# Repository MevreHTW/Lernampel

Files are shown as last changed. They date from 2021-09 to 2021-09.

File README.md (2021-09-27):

# Lernampel
Dieses Projekt wurde im Rahmen der Vorlesung Methoden der Wissensverarbeitung bei Frau Prof. Dr. Willner an der HTW Berlin umgesetzt. Zu dem Projektteam gehören: Mevre Tunca, Marianne Bähne, Martin König und Jonas Render.

Um den Code auf den Octopus zu flashen muss die Arduino IDE zuerst installiert werden. Die Aneitungen für die Installation finden sich hier:

Windows: https://www.umwelt-campus.de/fileadmin/Umwelt-Campus/IoT-Werkstatt/octopus/Quickstart.pdf

Mac: https://www.umwelt-campus.de/fileadmin/Umwelt-Campus/IoT-Werkstatt/octopus/QuickstartMacOS.pdf

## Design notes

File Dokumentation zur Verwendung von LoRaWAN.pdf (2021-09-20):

## Dokumentation zur Verwendung von LoRaWAN

Um die Lautstärke und Personenzahl von der Ampel und der Schranke in einem Dashboard darstellen zu können müssen sie per LoRaWAN versendet werden. Hierfür sollte zuerst der Account erstellt und das Gateway angeschlossen werden.

Erstellung einer Application/eines End devices auf thingsnetwork.org
Zur Erstellung einer Application den nachfolgenden Schritten folgen:
1. Auf der Website https://www.thethingsnetwork.org/ einen Account erstellen.
2. Auf den Accountnamen oben rechts klicken und dann Console auswählen. Account: jonasR95
pw: foddo0-giqraz-gAdbir
3. Europe 1 auswählen.
4. Go to Applications klicken.
5. Add Application klicken.
6. ApplicationID und Namen vergeben (kann individuell gewählt werden) und auf Create application klicken.
7. Add end device auswählen.
8. Bei Register end device in der Menüleiste manually auswählen und die Werte des Screenshots für LoRaWAN Version und Frequency plan auswählen, danach DevEUI, AppEUI und AppKey generieren lassen, falls gewünscht device ID anpassen.
9. Auf register end device klicken

Schritt 1:

Schritt 2:

Schritt 3:

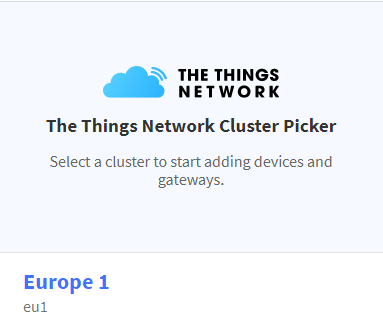
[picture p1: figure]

Schritt 4:

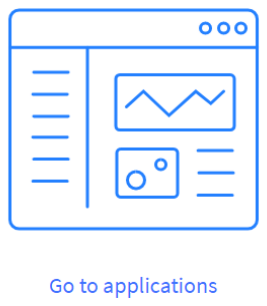
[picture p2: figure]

Schritt 5:

Schritt 6:

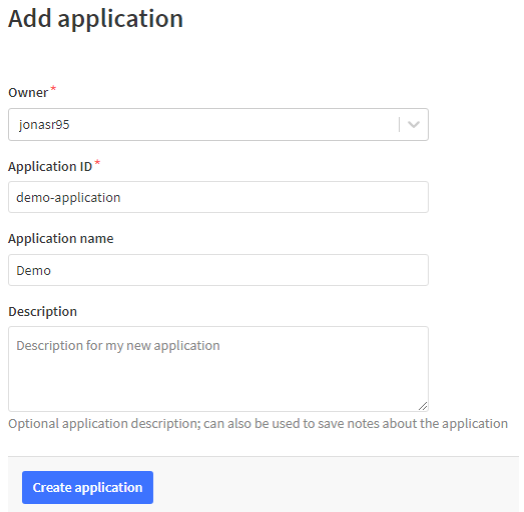
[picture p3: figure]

Schritt 7:

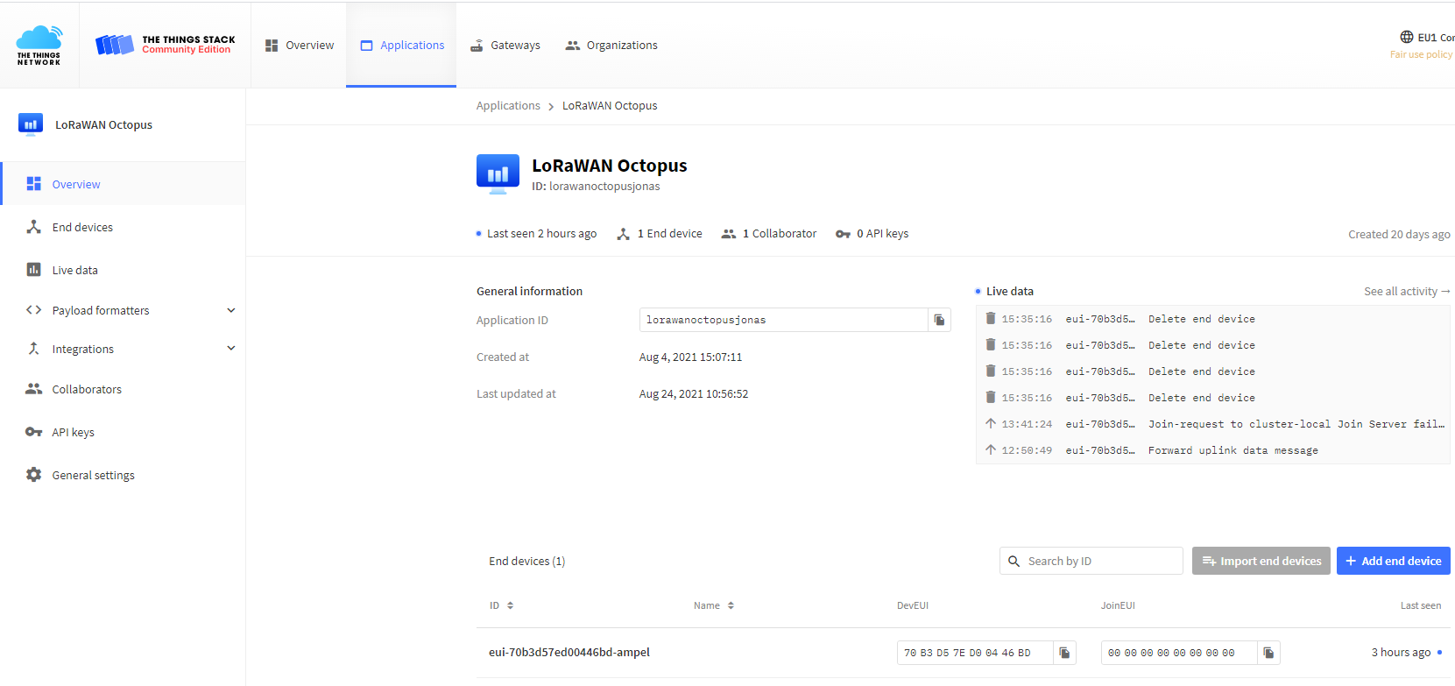
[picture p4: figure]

Schritt 8:

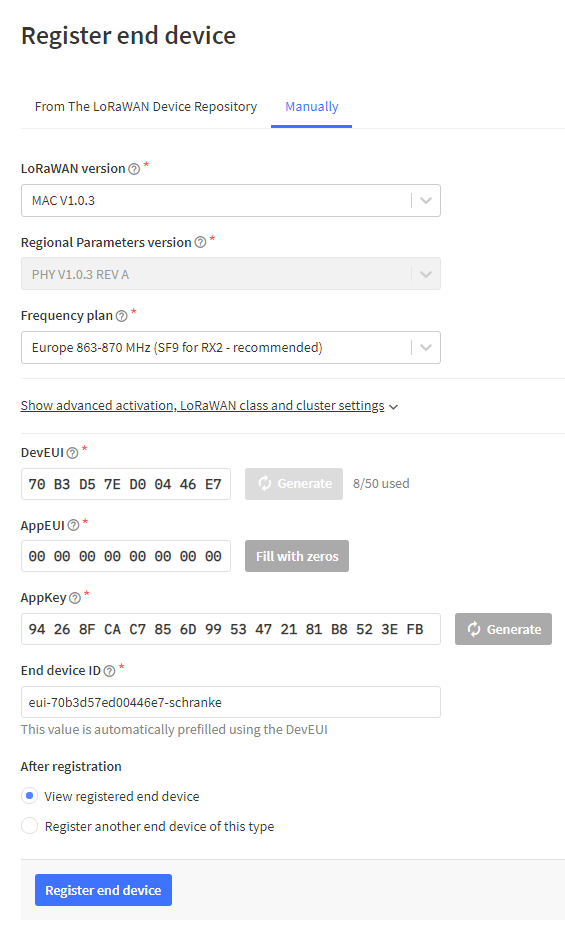
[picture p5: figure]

Einrichtung des LoRaWAN Gateways
Um die per LoRaWAN versendeten Daten im Internet sehen zu können müssen wir das LoRaWAN Gateway entsprechend einrichten. Hierfür wird das The Things Indoor Gateway benötigt. Zur Einrichtung bitte die folgenden Schritten befolgen:
1. Den RESET Button für 5 sekunden gedrückt halten bis die LED grün und rot blinkt.
2. Den SETUP Button für 10 sekunden gedrückt halten bis die LED rot blinkt.
3. Nach diesen Schritten befindet sich das Gateway im Einrichtungsmodus und sendet ein WiFi Signal.
4. Nach dem WiFi Netzwerk mit dem Namen MINIHUB-XXXXXX (das sind die letzten sechs stellen der Gateway EUI) suchen und mit dem Netzwerk verbinden.
5. Wenn eine Verbindung mit dem Netzwerk besteht im Browser 192.168.4.1 eingeben.
6. Auf der Seite das eigene Netzwerk suchen, auswählen und das Passwort für das Netzwerk eintragen.
7. Save & Reboot klicken.
8. Das Gateway startet neu und verbindet sich mit dem Netzwerk. Dafür einige Minuten warten, bis die Verbindung hergestellt wurde.

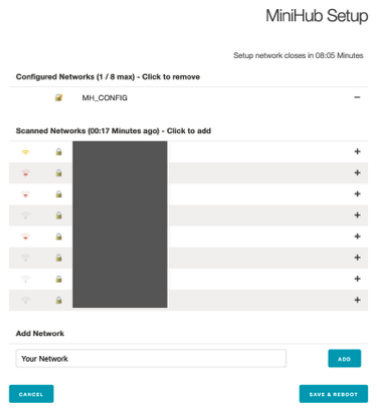
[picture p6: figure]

Quelle: https://www.thethingsindustries.com/docs/gateways/thethingsindoorgateway/

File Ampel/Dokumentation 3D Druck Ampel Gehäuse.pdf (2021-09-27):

## Dokumentation zum 3D Druck des Gehäuses für die Ampel

Was wird benötigt?
Um das Gehäuse drucken zu können wird ein 3D Drucker benötigt. Je nach Drucker unterscheidet sich die vorgehensweise, daher ist diese Anleitung sehr allgemein gehalten. 3 X .stl - Dateien (GitHub)
1 X Filament (schwarz)
1 X Filament (transparent)
8 X Gewindeeinsätze M3
6 X Schrauben M3 10 mm
2 X Schrauben M3 35 mm
1 X Spitzzange
1 X Teelicht

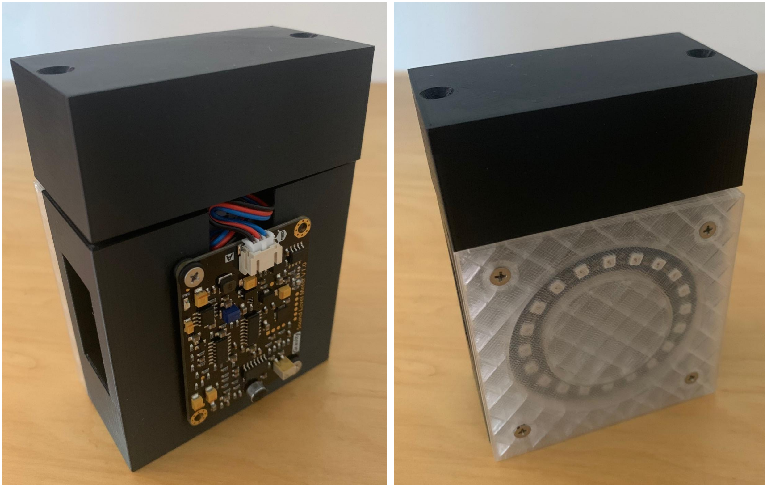
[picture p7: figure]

Druck der Dateien
Die .stl - Dateien aus GitHub herunterladen und slicen (je nach Drucker unterschiedliche vorgehensweise). Die beiden Dateien Ampel_Deckel und Ampel_Hauptteil sollten mit dem schwarzen Filament gedruckt werden. Die Datei Ampel_Abdeckung_LED Ring sollte mit dem transparenten Filament gedruckt werden.
Nach dem Druck aller drei Teile wie folgt vorgehen:
1. Eventuell müssen Stützstrukturen entfernt werden
2. Gewindeeinsätze in alle Löcher des Hauptteils montieren, hierzu:
a. Schraube in den Gewindeeinsatz eindrehen
b. Mit der Spitzzange die Schraube fixieren und den Gewindeeinsatz über dem Teelicht erhitzen
c. Gewindeeinsatz möglichst gerade in die jeweiligen Löcher des Hauptteils drücken
3. Hardware in die Hülle einbauen und mit den Schrauben fixieren. Der LED Ring kommt auf die Vorderseite (mit vier Schrauben), der Sensor zum Messen der Lautstärke auf die Rückseite (mit zwei Schrauben), hierfür die 10 mm Schrauben verwenden. Der Deckel wird mit den 35 mm Schrauben fixiert.

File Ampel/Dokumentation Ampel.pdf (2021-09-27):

## Dokumentation zur Entwicklung der Ampel

Was wird benötigt?
1 X IoT Octopus
1 X LoRa-Wings mit verlöteter Antenne
1 X Analog Sound Level Meter (https://www.mouser.de/ProductDetail/DFRobot/SEN0232?qs=r5DSvlrkXmJSkxvy12pSNQ%3D%3D)
1 X Grove - RGB LED Ring (20 - WS2813 Mini) (https://wiki.seeedstudio.com/Grove%20-%20RGB%20LED%20Ring%20%2820%20-%20WS2813%20Mini%29/) 2 X Jumper Kabel (digital)
1 X Jumper Kabel (analog)
3 X einfache Kabel
1 X Mini USB Kabel
1 X LoRaWAN Gateway - siehe Anleitung Dokumentation zur Verwendung von LoRaWAN

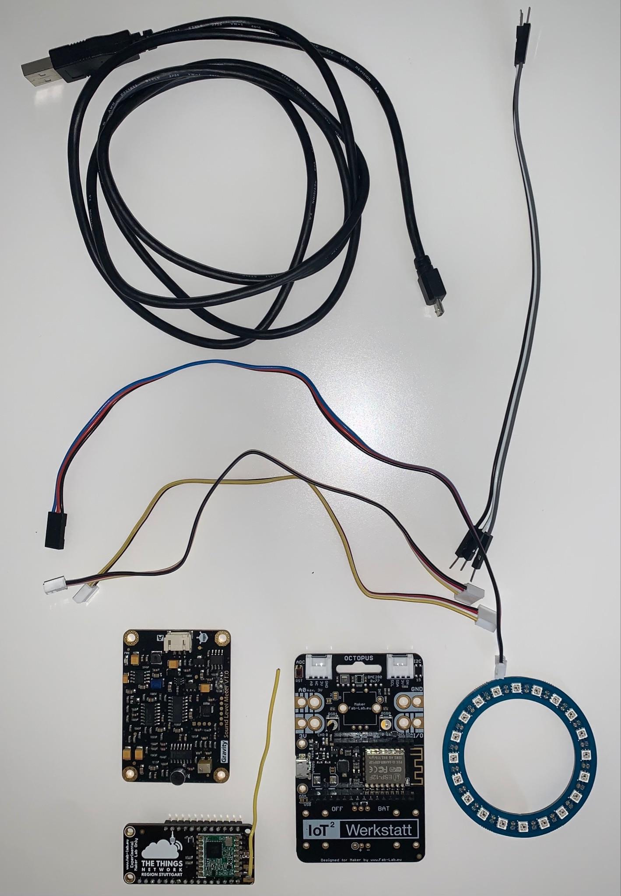
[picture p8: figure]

Allgemeine Hinweise und Funktionsweise der Ampel
Nachfolgend wird beschrieben wie die Hardware vorbereitet und der Code übertragen werden kann. Hierfür werden zunächst die Schritte erläutert und nachfolgend auch durch Bilder/Screenshots dargestellt.
Die Ampel misst die Lautstärke alle 250 Millisekunden. Je nach eingestellten Grenzwerten und aktueller Lautstärke leuchtet die Ampel rot, gelb oder grün. Alle 60 Sekunden wird die durchschnittliche Lautstärke mittels LoRaWAN versendet. Wenn dies geschieht leuchtet die Ampel blau, während dieser Zeit wird keine Lautstärke gemessen.

Hardware vorbereiten
Wir beginnen damit alle Bauteile an den Octopus anzuschließen. Hierbei wie folgt vorgehen:
1. LoRa-Wings auf den Octopus stecken.
2. Den LED Ring mit einem digitalen Jumper-Kabel mit dem Grove I²C Anschluss (oben rechts) verbinden.
3. Das analoge Jumper Kabel mit den Sound Sensor verbinden und das digitale Jumper Kabel mit dem analogen Anschluss des Octopus verbinden.
4. Nun das analoge - und digitale Jumper Kabel miteinander verbinden, hierzu die Beschriftung am Anschluss des Sound Sensors und Octopus beachten: (Achtung die Farben können je nach Kabel unterschiedlich sein)
Beschriftung am Sound Sensor | Beschriftung am Octopus
A (blau) | A0 (gelb)
+ (rot) | 3V (rot)
- (schwarz) | GND (schwarz)
nicht verbinden | NC (weiß)
5. Das Mini USB Kabel mit dem Octopus verbinden

Fotos zu den einzelnen Schritten:
Schritt 1:

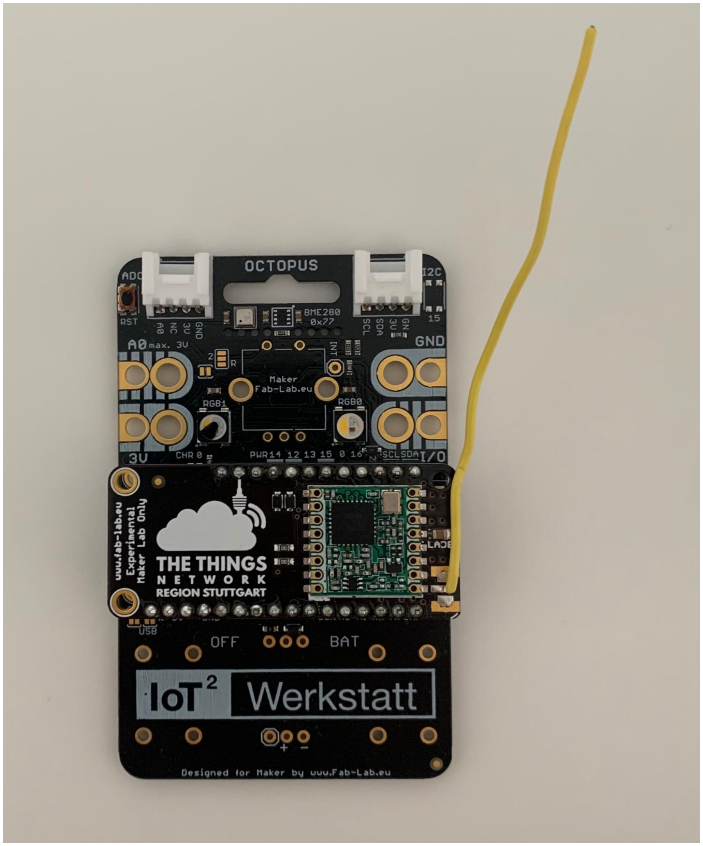
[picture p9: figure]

Schritt 2:

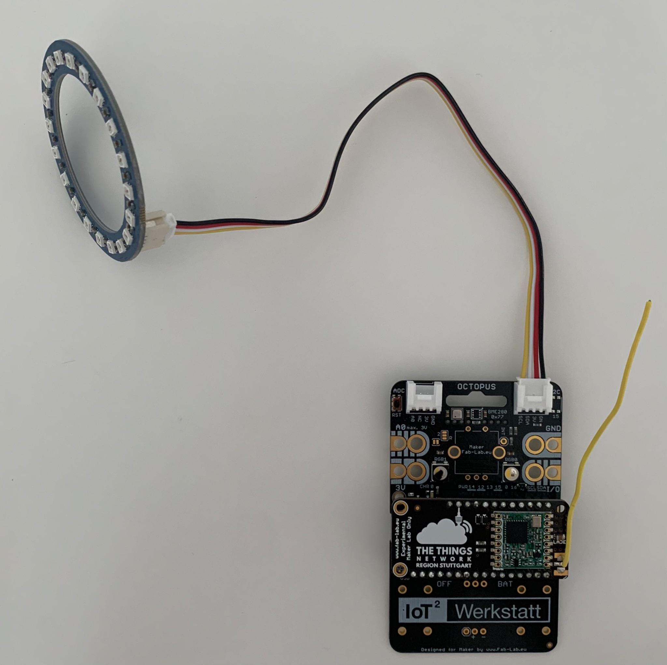
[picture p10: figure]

Schritt 3:

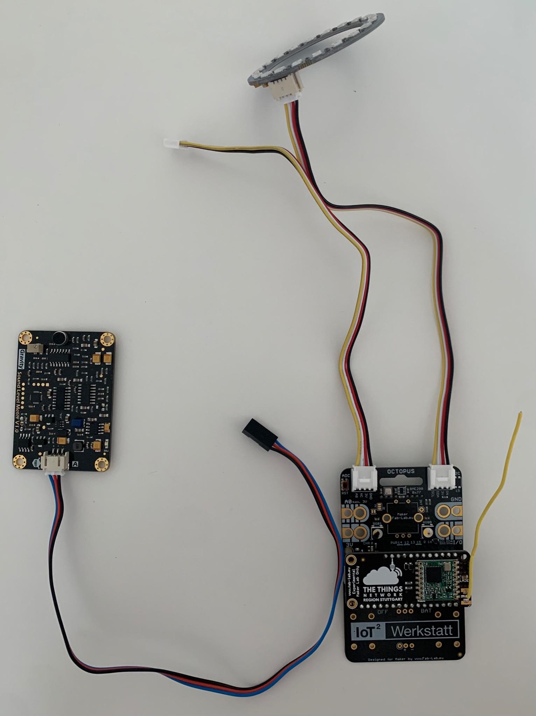
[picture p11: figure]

Schritt 4:

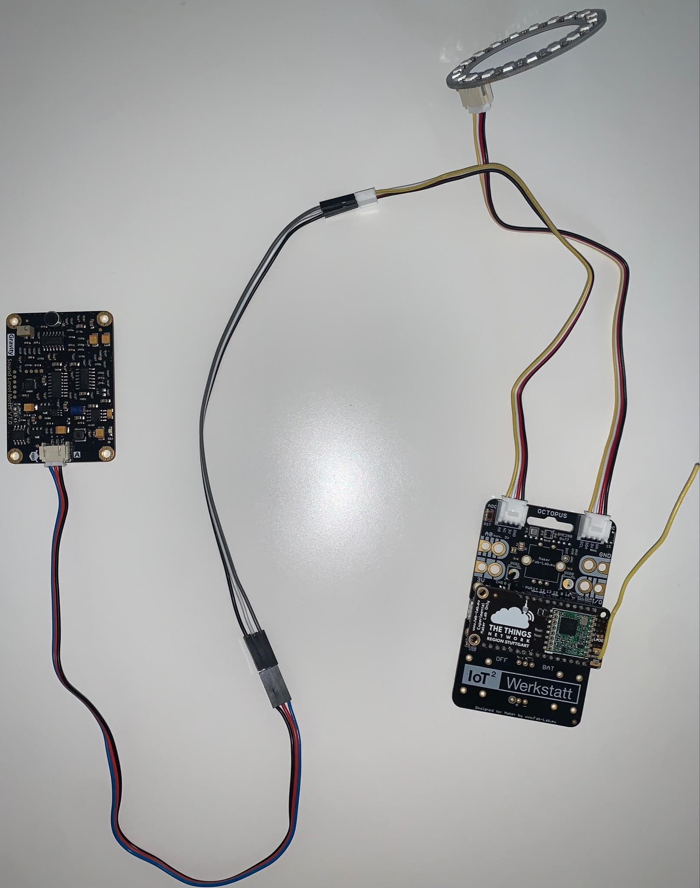
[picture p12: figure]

Anschluss am Sound Sensor:

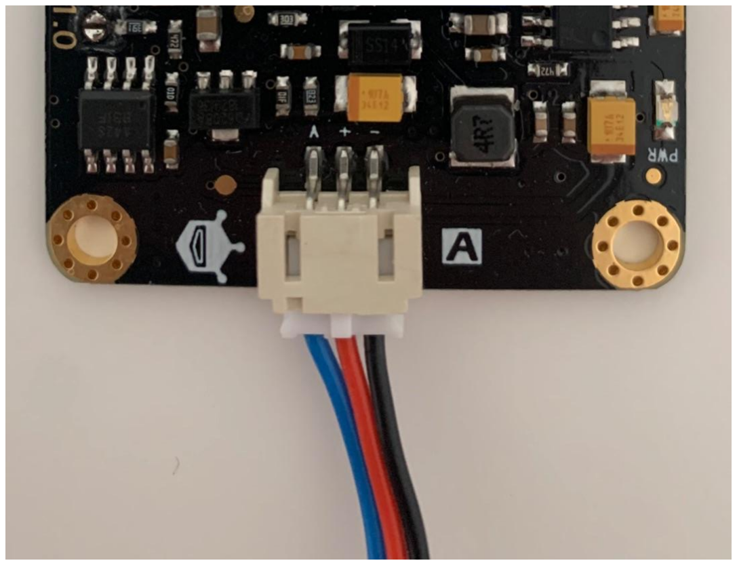
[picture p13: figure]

Anschluss am Octopus:

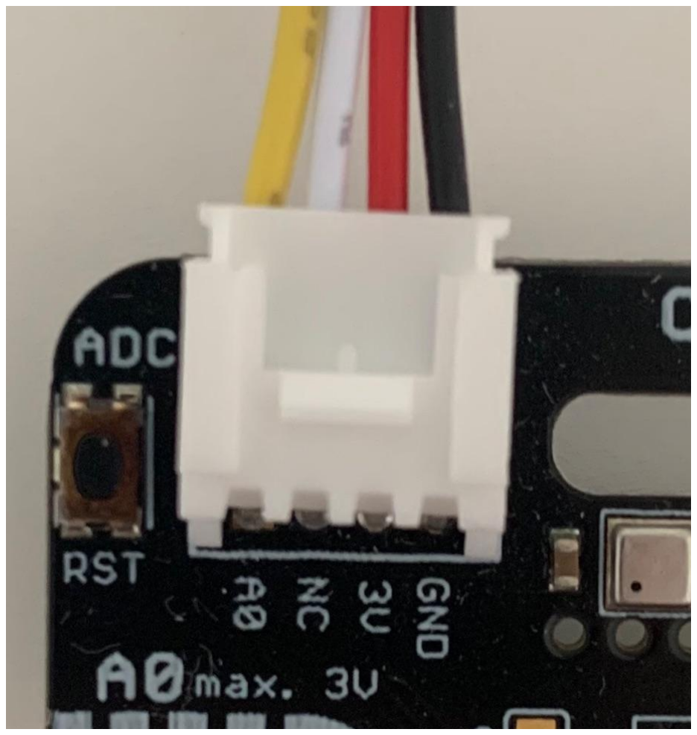
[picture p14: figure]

Schritt 5:

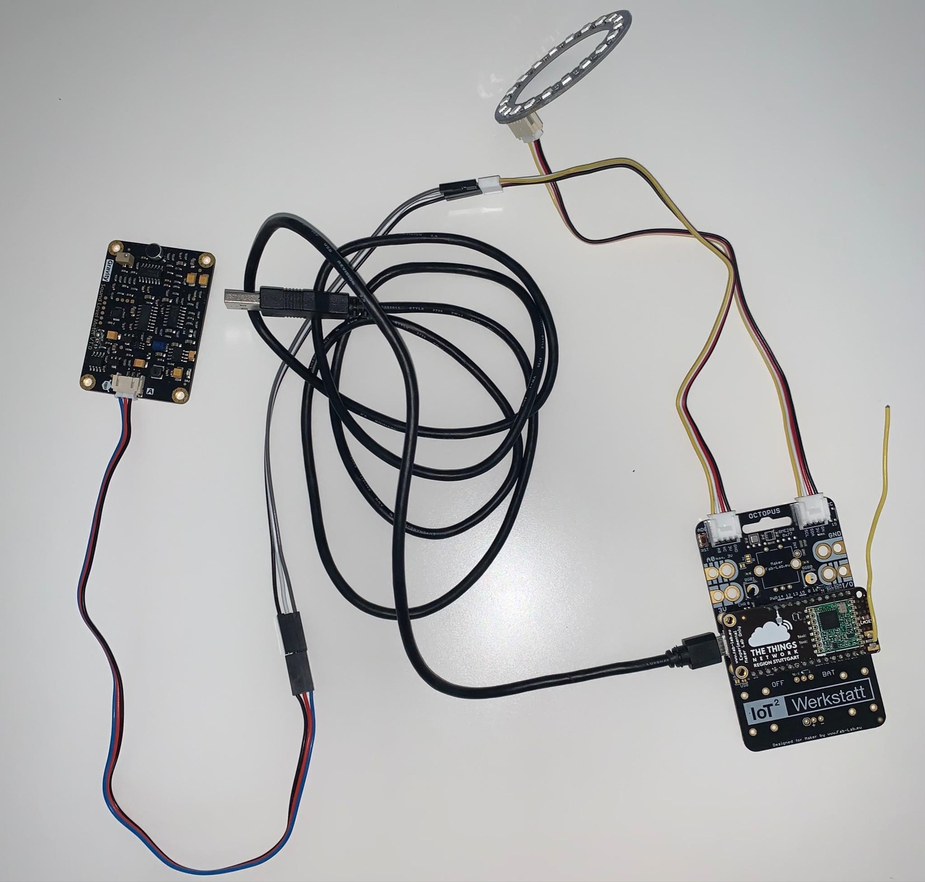
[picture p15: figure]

Code kopieren, vorbereiten und übertragen
Nachdem die Hardware miteinander verbunden wurde können wir den Code auf den Octopus übertragen. Hierbei wie folgt vorgehen:

Achtung: Bevor diese Schritte durchgeführt werden, sollte die Dokumentation zur Verwendung von LoRaWAN abgeschlossen sein.

1. Code kopieren:
https://github.com/MevreHTW/Lernampel/blob/main/Ampel/Code_Ampel.txt
2. Arduino IDE öffnen und eine neue Datei erstellen.
3. Alles markieren (Strg + A) und den Code einfügen.
4. Die Datei abspeichern.
5. Falls gewünscht die Grenzwerte für die Lautstärke anpassen (green, yellow, red).
6. Auf der Seite thethingsnetwork.org (https://eu1.cloud.thethings.network) das gewünschte end device auswählen.
7. Im Bereich Overview die AppEUI, DevEUI und den AppKey kopieren und im Code einfügen. Achtung, die richtige Formatierung (<>) und Sortierung lsb beachten!
8. Die Datei erneut speichern.
9. In der Arduino IDE unter Werkzeuge den Upload Speed auf 115200 stellen und den richtigen Port auswählen.
10. Das LoRaWAN Gateway an den Strom anschließen
11. Den Octopus über das USB Kabel mit dem Computer verbinden und den Code auf den Octopus übertragen.
12. Wenn die Übertragung abgeschlossen ist wird in der Konsole “Hard resetting via RTS pin …” angezeigt.
13. Auf Werkzeuge → Serieller Monitor klicken um die Ausgaben zu überwachen.
14. Auf der Seite hethingsnetwork.org (https://eu1.cloud.thethings.network) sollten die gesendeten Daten im Bereich Live data angezeigt werden.

Screenshots zu den einzelnen Schritten:
Schritt 1:

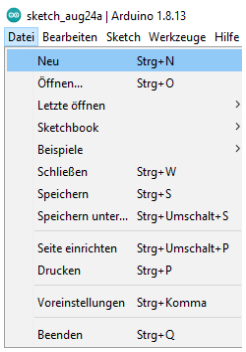
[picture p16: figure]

Schritt 2:

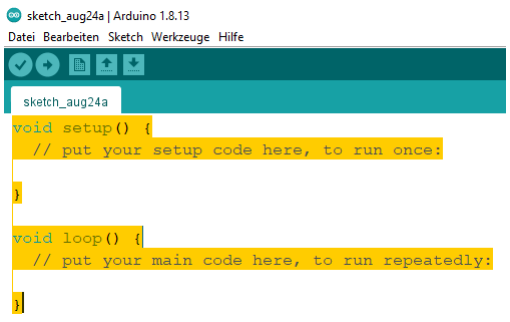
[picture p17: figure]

Schritt 4:

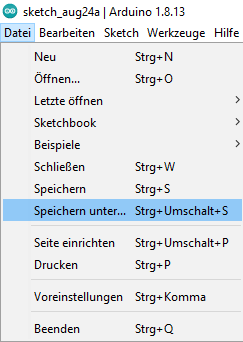
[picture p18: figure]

Schritt 5:

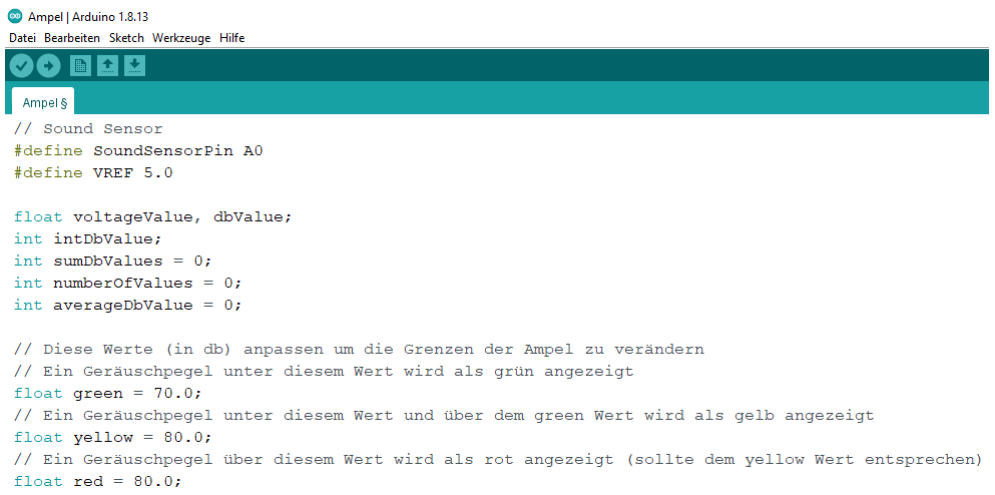
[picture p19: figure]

Schritt 6:

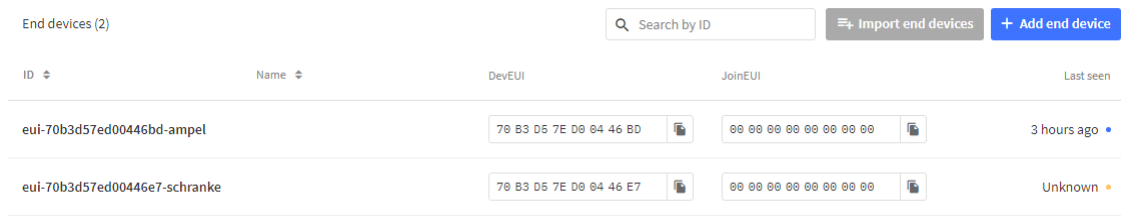
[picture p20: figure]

Schritt 7:

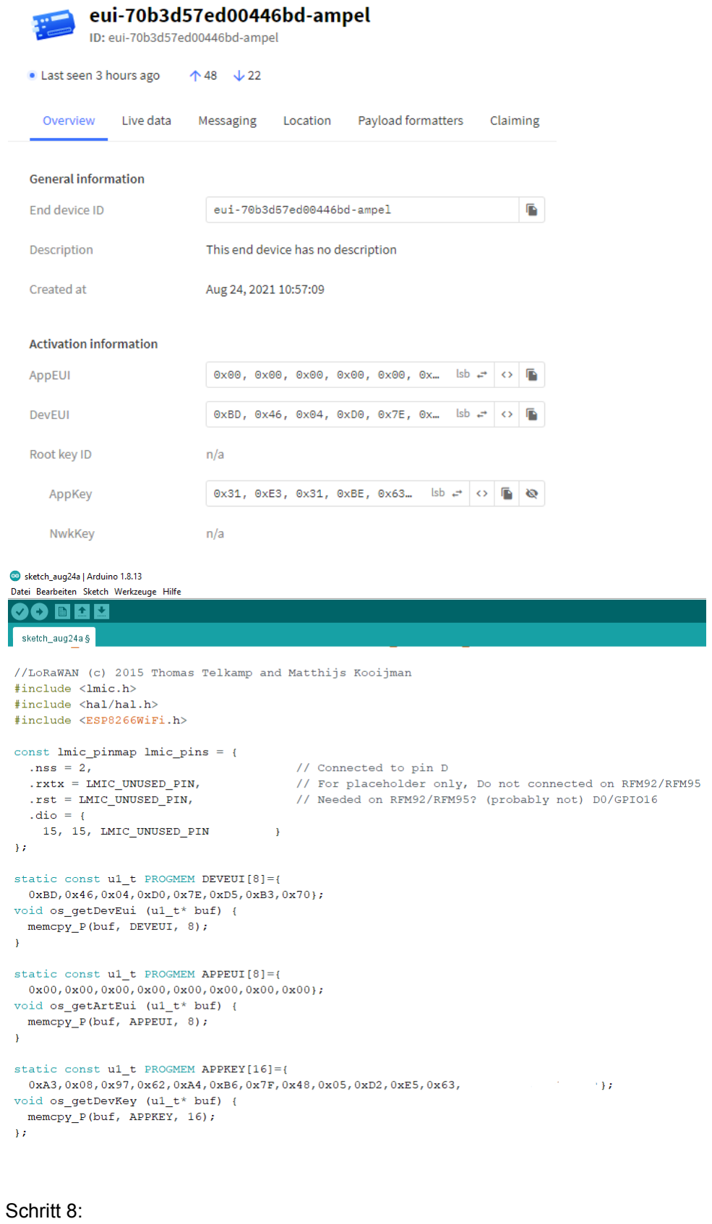
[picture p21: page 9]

Schritt 8:

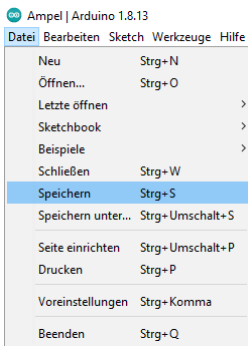
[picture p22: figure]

Schritt 9:

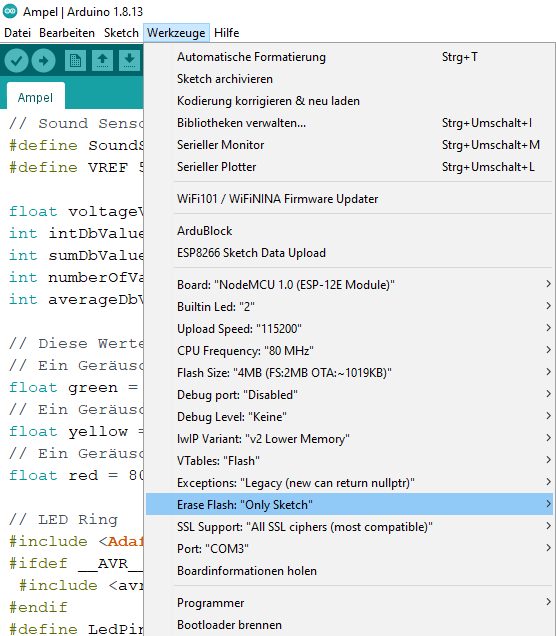
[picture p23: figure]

Schritt 10:

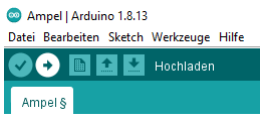
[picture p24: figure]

Schritt 11:

Schritt 12:


Schritt 13:


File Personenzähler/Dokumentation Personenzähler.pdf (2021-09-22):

Dokumentation Personenzähler

Was wird benötigt?

1 X IoT Octopus
1 X LoRa-Wings
4 X Jumper Kabel (digital)
2 x Ultrasonic Ranger Ultraschallsensor
1 X Mini USB Kabel
1 x HUB
1 x löten des gelben Kabels (für die Datenübertragung an den Port | 0 des
IoT Octopus)
1 X LoRaWAN Gateway - siehe Anleitung Dokumentation zur Verwendung von LoRaWAN


Allgemeine Hinweise und Funktionsweise der Schrank

Nachfolgend wird beschrieben wie die Hardware vorbereitet und der Code übertragen werden kann. Hierfür werden zunächst die Schritte erläutert und nachfolgend auch durch Bilder/Screenshots dargestellt.
Die Schranke misst die Anzahl der Menschen die sich in einem Raum befinden. Bei Anschluss der Schranke werden die Abstände, die die beiden Ultraschallsensoren messen als Grundwert genommen. Daher sollte die Schranke im Türrahmen so befestigt werden, dass die Sensoren die gegenüberliegende Türseite messen können. Verändert sich dieser Wert wird eine von zwei Möglichen Sequenzen ausgelöst. Ändert sich der gemessene Wert zuerst bei Sensor 1 und dann 2, geht eine Person in den Raum und die Zahl der gesamten Menschen erhöht sich um 1. Misst zuerst der Sensor 2 und dann 1 einen anderen Wert, verlässt jemand den Raum und die gesamte Anzahl reduziert sich um 1. Da sich nicht negativ viele Menschen in einem Raum befinden können, ist der default-Wert 0. Um die Berechnung richtig laufen lassen zu können, muss die Box daher so angebracht werden, dass das “OBEN” bei Anbringung an den Türrahmen gelesen werden kann. Ebenfalls sollte die Schranke an der rechten Türseite angebracht werden. Dabei ist die Ausgangsposition aus dem heraus.


Hardware vorbereiten
Wir beginnen damit alle Bauteile an den Octopus anzuschließen. Hierbei wie folgt vorgehen:

1. Datenkabel (gelb) des digitalen Jumpers an den Port 0 des Octopus löten
2. LoRA-Wings auf den Octopus stecken


3. Den HUB mit einem digitalen Jumper-Kabel mit dem Grove I²C Anschluss (oben


rechts) verbinden.

4. Einen der beiden Sensoren mit einem digitalen Jumper-Kabel mit dem HUB verbinden.


5. Den digitalen Jumper der mit dem gelben Kabel an den Octopus gelötet ist mit
6. Das Mini USB Kabel mit dem Octopus verbinden

Code kopieren, vorbereiten und übertragen
Nachdem die Hardware miteinander verbunden wurde können wir den Code auf den Octopus übertragen. Hierbei wie folgt vorgehen:

Achtung: Bevor diese Schritte durchgeführt werden, sollte die Dokumentation zur Verwendung von LoRaWAN abgeschlossen sein.

1. Code kopieren:
2. Arduino IDE öffnen und eine neue Datei erstellen.
3. Alles markieren (Strg + A) und den Code einfügen.
4. Die Datei abspeichern.
5. Falls gewünscht die Grenzwerte für die Lautstärke anpassen (green, yellow, red).
6. Auf der Seite thethingsnetwork.org (https://eu1.cloud.thethings.network) das gewünschte end device auswählen.
7. Im Bereich Overview die AppEUI, DevEUI und den AppKey kopieren und im Code einfügen. Achtung, die richtige Formatierung (<>) und Sortierung lsb beachten!
8. Die Datei erneut speichern.
9. In der Arduino IDE unter Werkzeuge den Upload Speed auf 115200 stellen und den richtigen Port auswählen.
10. Das LoRaWAN Gateway an den Strom anschließen
11. Den Octopus über das USB Kabel mit dem Computer verbinden und den Code auf den Octopus übertragen.
12. Wenn die Übertragung abgeschlossen ist wird in der Konsole “Hard resetting via RTS pin …” angezeigt.
13. Auf Werkzeuge → Serieller Monitor klicken um die Ausgaben zu überwachen.
14. Auf der Seite hethingsnetwork.org (https://eu1.cloud.thethings.network) sollten die gesendeten Daten im Bereich Live data angezeigt werden.

Screenshots zu den einzelnen Schritten:
Schritt 1:


Schritt 2:


Schritt 4:

Schritt 5:

Schritt 6:


Schritt 7:


Schritt 8:

Schritt 9:


Schritt 10:


Schritt 11:


Schritt 12:

Schritt 13:

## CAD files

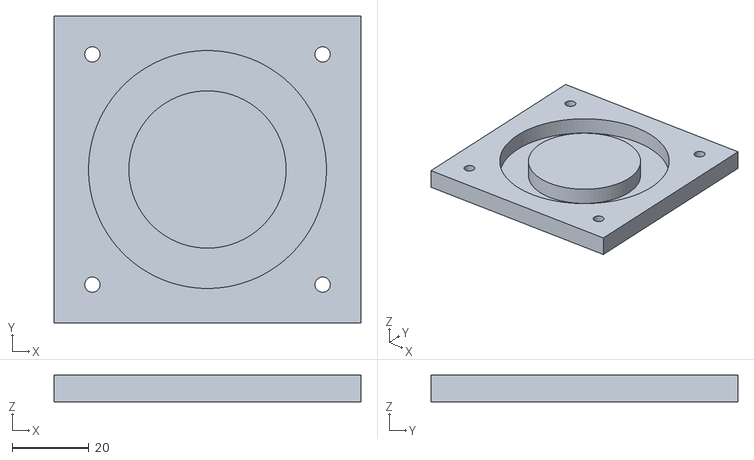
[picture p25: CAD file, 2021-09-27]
Ampel/Ampel_Abdeckung_LED Ring.stl
80.0 x 80.0 x 7.00

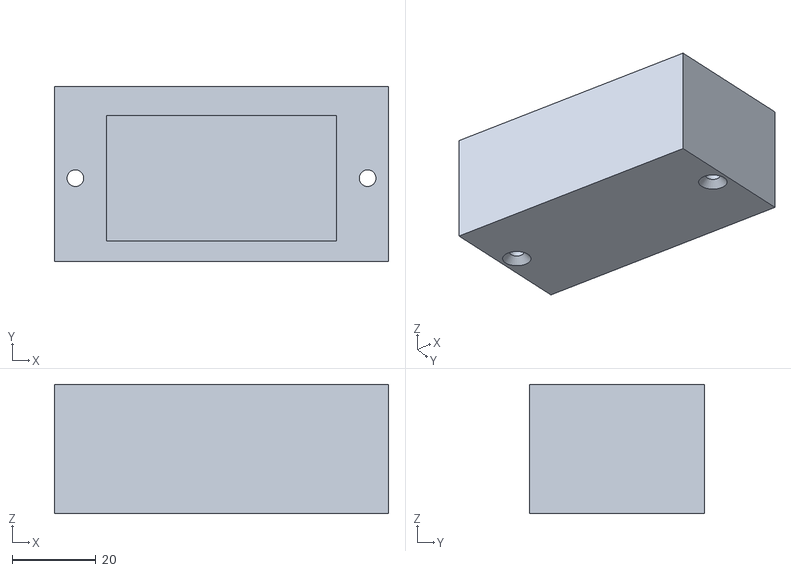
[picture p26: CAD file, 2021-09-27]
Ampel/Ampel_Deckel.stl
80.0 x 42.0 x 31.0

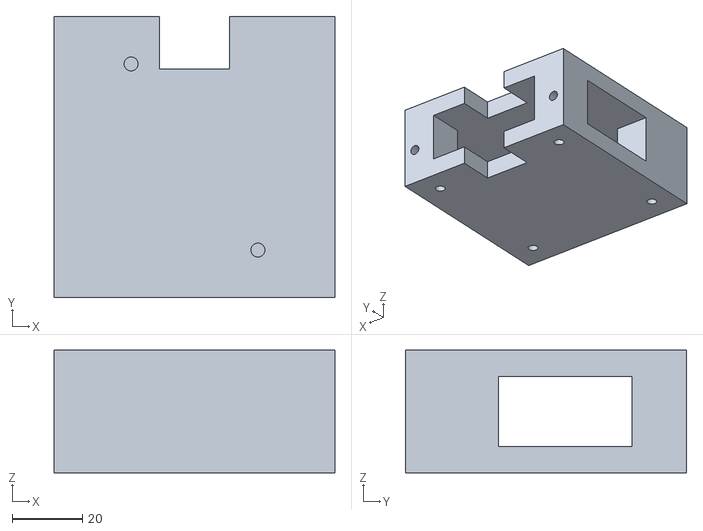
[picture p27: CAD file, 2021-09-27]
Ampel/Ampel_Hauptteil.stl
80.0 x 80.0 x 35.0
